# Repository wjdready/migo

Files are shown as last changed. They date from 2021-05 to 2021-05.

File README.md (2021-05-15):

## MiGo 开源掌机

这是一个迷你游戏机项目，[演示视频(bilibili)](https://www.bilibili.com/video/BV1qK4y1A7zA)，其目的是打造钥匙扣大小的功能齐全的掌机，同时也希望能兼顾掌机爱好者在它上面开发自己的应用。类似于 [Arduboy](https://github.com/Arduboy/Arduboy) 这个项目，它做的真的很好，很多的游戏爱好者在它上面开发了好几百个游戏，这主要归功于其简单的特性以及支持使用Arduino来开发自己的游戏。遗憾的是，Arduboy 局限于有限的机能（主控芯片为Atmega32u4，32kb falsh + 4kb SRAM），无法做出更好玩的功能。MiGO使用ESP32作为主控芯片，这款芯片功能强大但又足够简单上手，网上资源足够多，支持Arduino编程，所以就使用它了。

### 主要功能
MiGO 都有功能都有那些呢?以下是目前正在实现或者已经实现的一些，但实际上可以有更多的:
* fc 模拟器，对这是最基本的，实测运行帧率达60帧是完全没有问题的（屏幕分辨率240*240的情况下）
* gbc模拟器 目前网上已经有人在ESP32下实现gbc模拟器了，只需拿过来使用即可；
* gba模拟器 好吧，这个可能有些困难，因为性能可能还是不够，不过如果有人能够找出优化方案或许可以呢？
* sfc模拟器 这个模拟器可以做；
* arduboy模拟器 是的，你没有看错，MiGo其实可以运行Arduboy模拟器然后玩Arduboy游戏，真是非常不错
* xxx模拟器 更多模拟器可能会实现
* 音乐播放器，这个功能已经实现了，在使用软件解码mp3格式的情况下，播放48kHZ的音乐还是没有问题的
* 时间显示，这个功能因为加入了32.768kHz的晶振
* 录音功能, 因为 MiGo 主板上安装有一个MEMS传声器，所以可以用来录音并保存到内存卡；
* 网络通话， 得益于ESP32自带的WIFI功能，结合传声器和扬声器可以实现远程的网络语音聊天
* 游戏联机, 使用蓝牙或者wifi可以在nes模拟器上玩双人游戏；
* 网络收音机，通过wifi来连接Web Radio，这个已经实现了，让MiGO可以当不错的老人机；
* 网络音乐，已经有人通过esp32来播放网易云音乐，那么 MiGO 也一定行;
* 播放视频, 或许这个有一些困难，主要在于解码速率如何，不过值得一式；
* 远程投屏，这个还是挺有意思的，在电脑端搭建一个TCP服务器，MiGO通过WIFI接收电脑的屏幕信息，这个可以让MiGO和电脑互动。
* 无线手柄，MiGO可以通过蓝牙或者wifi来连接电脑来控制电脑上的游戏；
* 连接蓝牙耳机，虽然MiGO有一个3.5mm的耳机插孔，但是还可以通过蓝牙连接像airpod这样的蓝牙耳机；
* 网络电子书浏览器，利用LVGL可以实现一个非常精美的小说阅读器
* ftp文件服务器，web服务器 让MiGO连接上网站，并作为一个服务器，利用内网穿透，将你的网站发布的英特网；
* 英语词典，英语学习机，这个还可以用来学习，没想到吧；
* ... 太多, 省略

### Example
下面是MiGO运行fc模拟器的一个示意图:
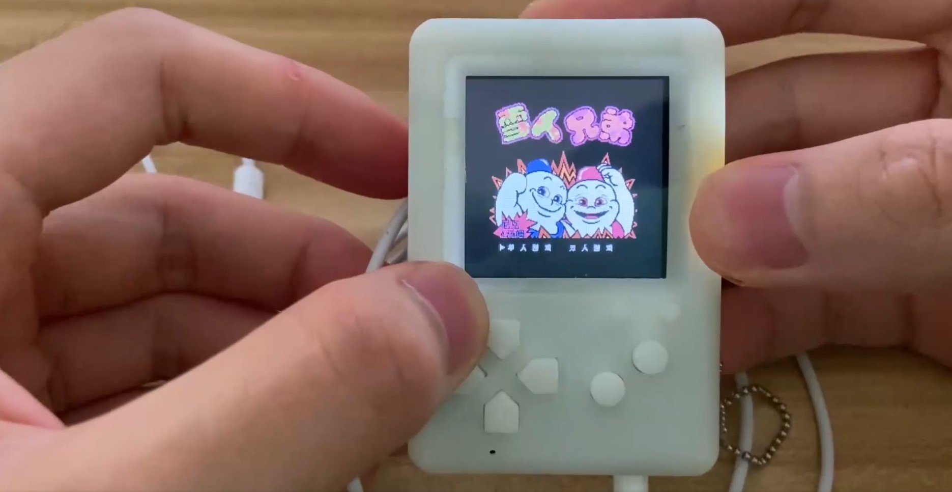
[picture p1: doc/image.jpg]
fc模拟器

看起来不错，小巧可爱的！但其实可以做的更小，但那就意味这电池容量不能做大太大，游玩时间缩短了。注意按键下面那个孔，它是用来录音的。旁边留有钥匙孔，可以穿钥匙扣。

### 文件说明
hardware 是硬件部分，里面包含了可以打印的3D外壳和Altium Designer工程文件，工程文件包含主板的整个工程文件和原理图，另外没有AD的话，里面的gerberfile_v4.0.zip可以直接发给PCB厂家打样,3D外壳可以使用3D打印机打印出外壳。

代码文件主要包含在两个文件夹，sdk是MiGO应用开发的软件开发工具包，里面包含MiGO的硬件驱动和UI库，应用通过调用SDK的接口来实现各种功能而不用关系底层问题。migo文件夹是各种应用所在的目录。你也可以自己创建一个文件夹来创建应用，只需要在makefile 中指定sdk组件的目录即可。
```makefile
EXTRA_COMPONENT_DIRS := ../sdk
```

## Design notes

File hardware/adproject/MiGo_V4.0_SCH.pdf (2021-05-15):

# 22pF XTAL_P XTAL_N

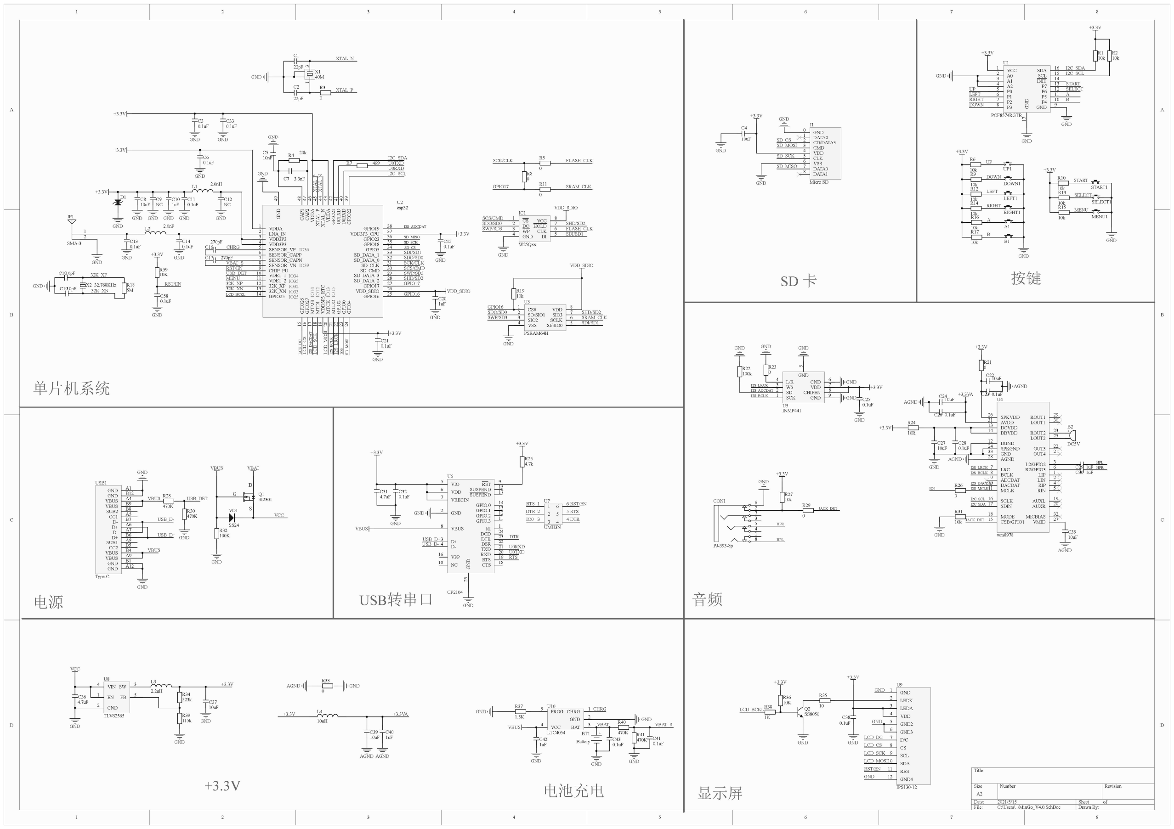
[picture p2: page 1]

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
Title

Size | Number | | Revision
A2
Date: | 2021/5/15 | Sheet | of
File: | C:\Users\..\MinGo_V4.0.SchDoc | Drawn By:

VDDA 1
LNA_IN 2
VDD3P3 3
VDD3P3 4
SENSOR_VP 5
SENSOR_CAPP 6
SENSOR_CAPN 7
SENSOR_VN 8
CHIP_PU 9
VDET_1 10
VDET_2 11
32K_XP 12
32K_XN 13
GPIO25 14 | GPIO²⁶ 15 GPIO²⁷ 16 MTMS 17 MTDI 18 VDD³P³_RTC 19 MTCK 20 MTDO 21 GPIO² 22 GPIO⁰ 23 GPIO⁴ 24
GPIO16 | 25 VDD_SDIO | 26 GPIO17 | 27 SD_DATA_2 | 28 SD_DATA_3 | 29 SD_CMD | 30 SD_CLK | 31 SD_DATA_0 | 32 SD_DATA_1 | 33 GPIO5 | 34 GPIO18 | 35 GPIO23 | 36 VDD3P3_CPU | 37 GPIO19 | 38 GPIO²² ³⁹ U⁰RXD ⁴⁰ U⁰TXD ⁴¹ GPIO²¹ ⁴² VDDA ⁴³ XTAL_N ⁴⁴ XTAL_P ⁴⁵ VDDA ⁴⁶ CAP² ⁴⁷ CAP¹ ⁴⁸ GND ⁴⁹ | U2

esp32

+3.3V
C21
0.1uF

GND

GPIO16

SDI/SD1
SDO/SD0
SCK/CLK
SCS/CMD
SWP/SD3
MENU | SHD/SD2

RST/EN

VBAT_S

+3.3V
C15
0.1uF

GND

VDD_SDIO
C20
1uF

GND

+3.3V

L1 2.0nH

C12
NC
| GND

C11
0.1uF

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
10uF
GND | CS 1
DO 2
WP 3
GND 4 | DI | 5
| CLK | 6
HOLD | 7
VCC | 8

IC1

W25Qxx

SCS/CMD

FLASH_CLK

R5

0

R11

0

FLASH_CLK

SRAM_CLK

SCK/CLK

SHD/SD2

SDI/SD1

VDD_SDIO

GND

SWP/SD3

SDO/SD0

CS# 1
SO/SIO1 2
SIO2 3
VSS 4
SI/SIO0 | 5
SCLK | 6
SIO3 | 7
VDD | 8

U3

PSRAM64H

GPIO16
SDO/SD0
SWP/SD3

GND

VDD_SDIO

R19
10k

SHD/SD2
SRAM_CLK
SDI/SD1
+3.3V | 1 3 | X1
GND | 40M
| | R3
| | 0

C2

22pF

C1

XTAL_P

XTAL_N

+3.3V
C6
0.1uF

GND

C3
0.1uF

GND

L2 2.0nF

C14
0.1uF
| GND

C13
0.1uF

GND

C16

270pF

C17 270pF

GND

R4 20k

C7 3.3nF

GND

C5
10nF
R7 | 499 | U0TXD U0RXD

I2C_SDA

I2C_SCL

GND | A1
GND | B12
VBUS | A4
VBUS | B9
SUB2 | B8
CC1 | A5
D- | B7
D+ | A6
D- | A7
D+ | B6
SUB1 | A8
CC2 | B5
VBUS | B4
VBUS | A9
GND | B1
GND | A12

USB1

Type-C

GND

GND

VBUS

VBUS

USB_D-

USB_D+

D
G

S

Q1
SI2301

VD1

SS24

VBUS

GND

R32
100K

VBAT

R37

1.5K

PROG 5

VCC 4

CHRG | 1
GND | 2
BAT | 3

U10

LTC4054

VCC

VBAT VBUS

C42
1uF

GND

GND | CHRG

IO33

IO34
IO35
IO32

IO25

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
UMH3N

VIO 5
VDD 6
VREGIN 7

GND 2

VBUS 8

D+ 3
D- 4

VPP 16

NC 10 | CTS | 18 RTS | 19 RXD | 20 TXD | 21 DSR | 22 DTR | 23 DCD | 24 RI | 1
GPIO.3 | 11 GPIO.2 | 12 GPIO.1 | 13 GPIO.0 | 14
SUSPEND | 17 SUSPEND | 15 RST | 9 GND 25

U6

CP2104

RTS
DTR
IO0 | DTR RTS

DTR

U0RXD
U0TXD
RTS

C32
0.1uF

C31
4.7uF

+3.3V

GND

GND

VBUS

USB_D+
USB_D-

+3.3V

R25
4.7k

RST/EN

GND 1
LEDK 2
LEDA 3
VDD 4
GND2 5
GND3 6
D/C 7
CS 8
SCL 9
SDA 10
RES 11
GND4 12

U9

IPS130-12

Q2
SS8050

R36
10K

+3.3V

C38
0.1uF

GND

R35

10

+3.3V

R38

1K

LCD_BCKL

GND

GND

LCD_SCK

LCD_CS

LCD_DC

RST/EN
GND

LCD_MOSI

GND

+3.3V

UP1

R6

10k

DOWN1

R9

10k

LEFT1

R12

10k

RIGHT1

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
+3.3V

START1

R10

10k

SELECT1

R13

10k

MENU1

R15

10k

GND

BT1 +
Battery

GND

GND

C43
0.1uF

R40

470K R41 470K

GND

C41
0.1uF

VBAT_S

R28

470K
R30
470K

GND

USB_DET | IO¹⁴ IO¹² | IO¹³ IO¹⁵

A

B

SELECT

START

LEFT

DOWN

UP

MENU

RIGHT

GPIO17

GPIO17

R8
0

# 单片机系统

电源 | USB转串口
+3.3V | 电池充电 | 显示屏

音频

SD 卡 | 按键

2

1

JP1

SMA-3

GND

D1

GND

GND

VCC 1
A0 2
A1 3
A2 4
P0 5
P1 6
P2 7
P3 8 | GND | 9
P4 | 10 P5 | 11 P6 | 12 P7 | 13 INIT | 14 SCL | 15 SDA | 16 GND 17

U1

PCF8574RGTR

GND

GND

R2
10k

R1
10k

+3.3V

I2C_SCL

I2C_SDA

DOWN

GND

+3.3V

X2 32.768KHz

C1810pF

C1910pF GND

32K_XP

32K_XN

32K_XP
32K_XN

R18
5M
LIP | 1
LIN | 2
L2/GPIO2 | 3
RIP | 4
RIN | 5
R2/GPIO3 | 6 LRC 7
BCLK 8
ADCDAT 9
DACDAT 10
MCLK 11

DGND 12

DCVDD 13
DBVDD 14

CSB/GPIO1 15

SCLK 16
SDIN 17

MODE 18

AUXL | 19
AUXR | 20
OUT4 | 21 OUT3 | 22
ROUT2 | 23

SPKGND 24

LOUT2 25

SPKVDD 26

VMID 27

AGND 28

ROUT1 | 29
LOUT1 | 30 AVDD 31
MICBIAS | 32

GND 33

U4

wm8978

+3.3VA C2410uF

C26 0.1uF

AGND

+3.3V

C2210uF

C23 0.1uF

R21
0

AGND

+3.3V

R24

10R

C27
10uF

C28
0.1uF

GND

AGND
C29 1uF

HPL

C30 1uF

HPR

C35
10uF

AGND

+

B2

DC5V

JACK_DET

R31

10k

GND

I2S_LRCK
I2S_BCLK

I2S_DACDAT
I2S_MCLK

I2C_SCL
I2C_SDA

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
CON1

PJ-393-8p

R27
10k

+3.3V

HPR

HPL

R29

0

JACK_DET

R26

0

IO0

GND

SCK 1

SD 2 WS 3

L/R 4

GND⁵

GND | 6
VDD | 7
CHIPEN | 8
GND | 9

U5
INMP441

GND

I2S_LRCK
I2S_ADCDAT

GND

GND

+3.3V

R22
100k

C25
0.1uF

GND

GND

DATA2 1
CD/DATA3 2
CMD 3
VDD 4
CLK 5
VSS 6
DATA0 7
DATA1 8

GND 0

J1

Micro SD

SD_CS
SD_MOSI

+3.3V

C4

10uF

GND
SD_SCK

GND

SD_MISO

GND

L4

10uH

+3.3V

C39
10uF

C40
1uF

AGND AGND

+3.3VA

R33

0

AGND | GND

R39
115k

GND

VIN 4

EN 1

GND 2

FB | 5
SW | 3

U8

TLV62565

GND

R34
523k

GND

+3.3V

VCC

L3

2.2uH
C36
4.7uF | C37
| 10uF

+3.3V

R59
10K

C58
0.1uF

GND

RST/EN

IO39

IO36

USB_DET

CHRG

R23
0

GND
I2S_BCLK IO⁰

C33
0.1uF

GND

LCD_BCKL | LCD_DC LCD_CS

I2S_ADCDAT I2S_DACDAT LCD_SCK

SD_SCK LCD_MOSI I2S_BCLK I2S_LRCK

START
UP | SELECT
LEFT
RIGHT | B

A SD_MOSI

SD_MISO

SD_CS

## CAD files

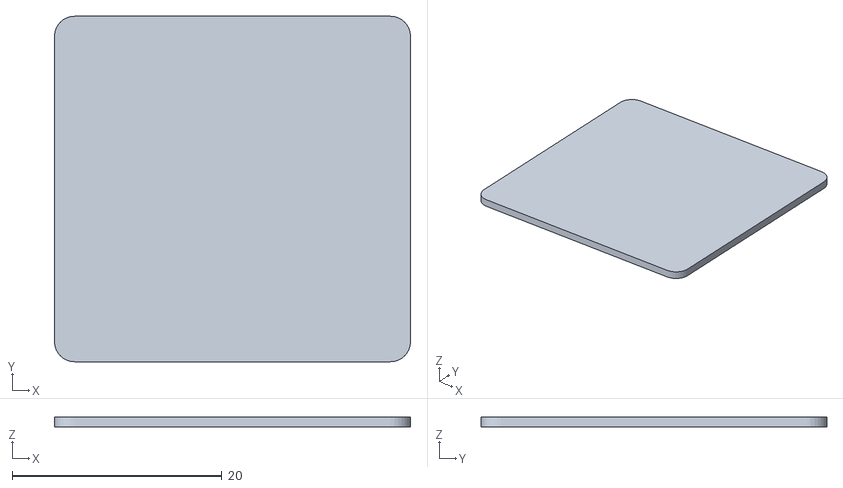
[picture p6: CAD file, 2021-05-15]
hardware/3d_file/yakeli.stl
33.9 x 32.9 x 1.00

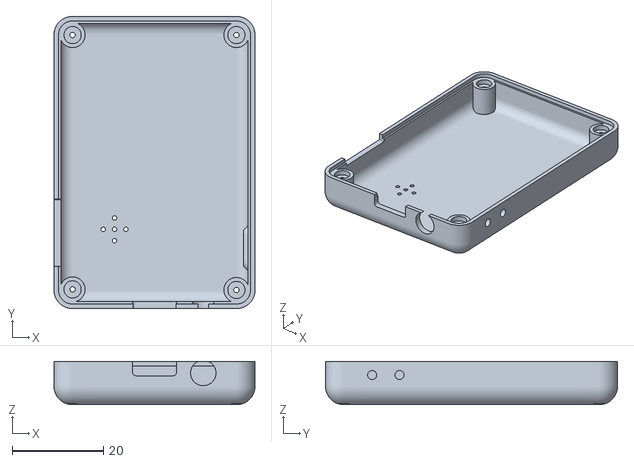
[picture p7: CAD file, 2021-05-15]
hardware/3d_file/xiake.stl
44.2 x 64.2 x 9.50

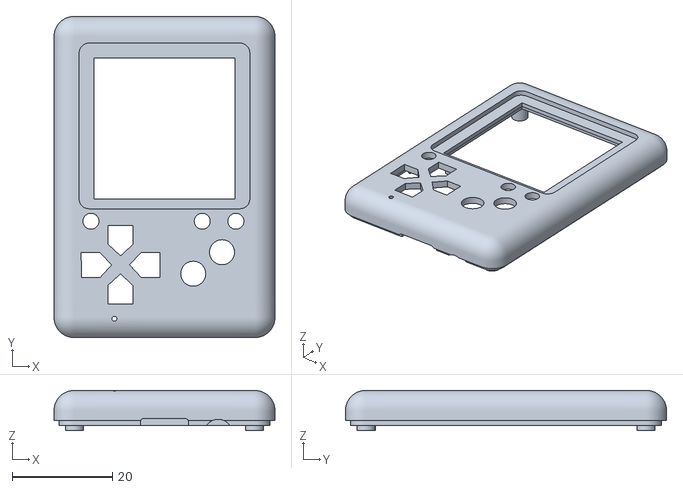
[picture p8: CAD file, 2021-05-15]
hardware/3d_file/shangke.stl
44.2 x 64.2 x 8.00

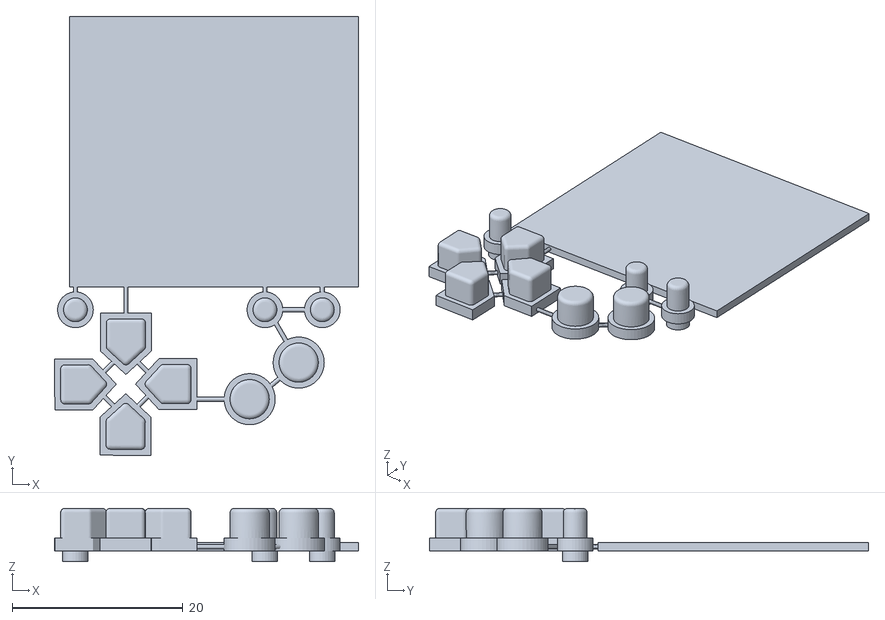
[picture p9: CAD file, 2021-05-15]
hardware/3d_file/anjian.stl
35.7 x 51.5 x 6.25

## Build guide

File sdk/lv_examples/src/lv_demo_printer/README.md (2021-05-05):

# Printer demo

## Overview
A printer example created with LVGL. This demo is optmized for 800x480 resolution and among many others it demonstrates custom theme creation, style transitions and animations. 

The demo uses some images with 32 bit color depth they require ~1.6 MB flash. With 16 bit color depth ~900KB is required for the images.

Printer demo with LVGL embedded GUI library

## Run the demo
- In `lv_ex_conf.h` set `LV_USE_DEMO_PRINTER 1`
- After `lv_init()` and initializing the drivers call `lv_demo_printer()`

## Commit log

2021-05-15 add hardware, readme
    [MiGo_V4.0.PrjPCB, MinGo_V4.0.SchDoc, anjian.stl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]
2021-08-22 添加 Windows 环境支持
